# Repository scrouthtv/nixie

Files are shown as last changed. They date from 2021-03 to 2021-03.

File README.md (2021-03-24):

# About VFD tubes

<!--![Principle of VFD operation](./sources/futaba_concept.jpg)-->
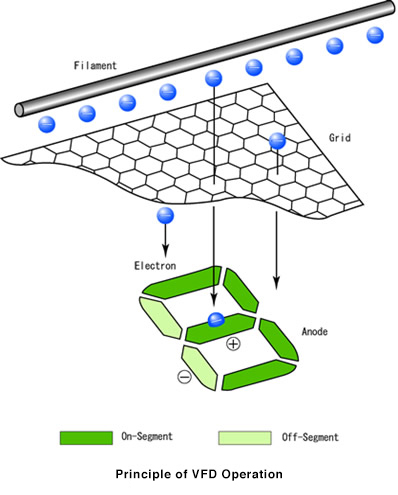
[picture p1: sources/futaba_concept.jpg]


The manufacturer has a [good explanation of the concept of VFD tubes](http://futaba.co.jp/en/display/vfd/index.html) on their website.

They basically work like this:
1. A *filament* (usually a Tungsten wire) is heated up and emits electrons into the vacuum in the tube.
2. The electrons are accelerated through a *grid* towards a positive-charged *anode*.
3. The electrons collide with the phosphor-coated anode and emit light due to [fluorescence](https://en.wikipedia.org/wiki/Fluorescence).

In the simplest case, the anodes make up an 8-figure consisting of seven individual segments plus a decimal point as an eigth segment.
[More complicated designs](http://futaba.co.jp/en/display/vfd/applications.html) such as combining multiple letters of different size, adding in symbols or [colors](https://en.wikipedia.org/wiki/Phosphorescence#Materials).

Each anode has its own wire leaving the casing.
The whole tube must be "activated" by setting the grid to a higher potential compared to the filament, which allows for multiplexing multiple tubes.

Image Source: [VFD | Futaba Corporation](http://futaba.co.jp/en/display/vfd/index.html)

# The tubes

I recently got ten VFD tubes labelled as **Futaba DG10Q1 3GS** out of an old calculator that was due for trash:

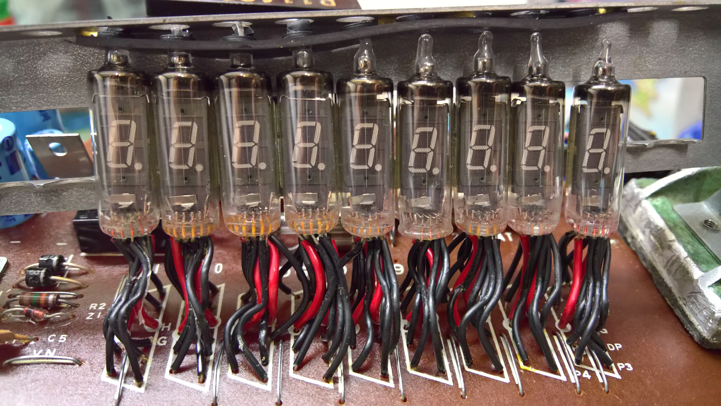
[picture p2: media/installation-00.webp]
The tubes installed in the calculator


The manufacturer has been ["selling gas-discharge display tube [since] 1968"](http://futaba.co.jp/en/files/notice_20200805.pdf). Sadly, they want to leave the business until the end of this year (2021).

The tubes themselves look fantastic:

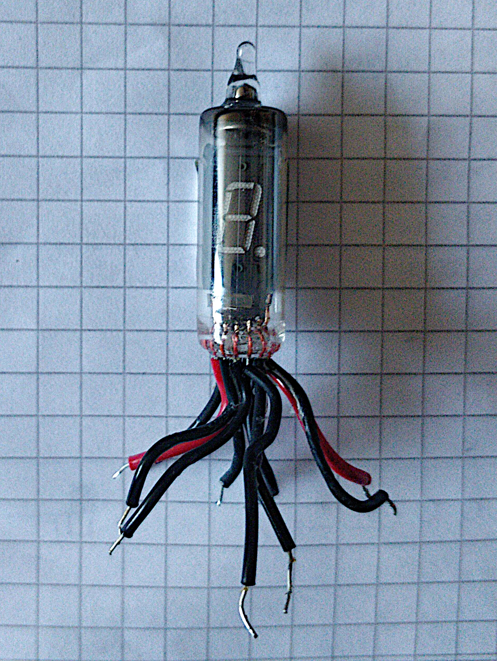
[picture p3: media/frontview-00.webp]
Frontview of the DG10Q1


Image Source: Used with permission, own work.

## Testing a tube

I wasn't able to find a datasheet online, only this image that circulates on the internet:

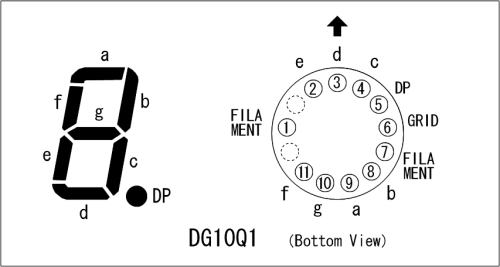
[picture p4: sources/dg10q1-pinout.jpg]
Pinout of the DG10Q1, bottom view


**Keep in mind that this is the bottom view.**

The filament in this tube is a thin wire in the front center that runs from the bottom to the top.
It glows orange-ish after applying a high enough current to it. 

My tubes have a set of red-colored wires for the filament. If yours don't, try to find the pair of pins wich has the lowest resistance (lower than 10 ohms). 

Slowly increasing the voltage across these two pins, they started glowing at around 0.8 V.

As a next step, I applied 18 V to both the grid and a segment to see it glowing.

Image Source: [DG10Q1 | AsahiNet](https://ne.jp/asahi/shared/o-family/ElecRoom/PARTS/DISPLAY/ElDG10Q1.html)

# My final circuit

I am planning on combining multiple tubes to get a "smart" clock which is controlled by an atmega328 chip (the chip that is also used in an Arduino).
The atmega can then be combined with a Raspberry Pi which controls the displayed text. 

In the end, I'll need at least a 5 V power supply for the logic.

## The filament driver

The filament basically carries all the load of the tube.
I found that a single DG10Q1 consumes up to 50 mA at 1 V!

The easiest way would be to use a voltage regulator which creates 1 V from my 5 V supply.
However, many common voltage regulators use a reference voltage of 1.25 V (e.g. [LM317](https://ti.com/lit/ds/symlink/lm317.pdf) or [MAX1733](https://datasheets.maximintegrated.com/en/ds/MAX1733-MAX1734.pdf)) and can't be adjusted to anything below 1.25 V ([without an overly complicated circuit](https://electronics.stackexchange.com/questions/116842/very-low-voltage-regulator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)).

Because of this issue, I am using a type of [current mirror circuit](https://wiki.analog.com/university/courses/electronics/text/chapter-11) instead:

Circuit used as the filament driver

Technically, it is used to mirror the amps from an input to the output.

However, with the correct value for R3, an arbitrary output voltage can be set.

*TODO: this is not correct and needs more work*

Image source: Own work.

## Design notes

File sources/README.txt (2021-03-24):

Further Reading
===============

*Nothing* in this folder is provided with permission of the original author.
I simply documented some things I came across that I found interesting, in case the original got taken down.

Sources:
 - futaba_vfd.pdf: http://futaba.co.jp/en/display/vfd/index.html. The original article on Futaba's website about the working principle of VFD tubes.
 - futaba_concept.jpg: http://futaba.co.jp/en/dbps_data/_material_/radicon_eng/Display_and_Module/vfd/images/whats_vfd02.jpg. The image along with the article.
 - futaba_vfd_applications.pdf: http://futaba.co.jp/en/display/vfd/applications.html. A glimpse at what can be done with VFD tubes.
 - dg10q1-pinout.jpg: Appears on https://ne.jp/asahi/shared/o-family/ElecRoom/PARTS/DISPLAY/ElDG10Q1.html as well as https://surplussales.com/Bulbs-Incan-Panel/Close-ups/lmp-dg10a.html and https://radiomuseum.org/tubes/tube_dg10q1.html. Pinout for a DG10Q1 or comparable, bottom view.

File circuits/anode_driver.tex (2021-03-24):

\documentclass[margin = 24mm]{standalone}

\usepackage{xcolor}

\usepackage{mathspec}
\setallmainfonts(Digits,Latin){osifont.ttf}

\usepackage{siunitx}
\sisetup{locale = DE, retain-explicit-plus}

\usepackage[european]{circuitikz}

\begin{document}
	\begin{circuitikz}[]
		\node [nigfete] (fet) at (3, -.75) {Q};
		\draw (0, -1) to [short, o-] (fet.G);
		\node [above] at (0, -1) { \SI{+5}{\volt} };

		\node [diodetube, filament, nocathode] (tube) at (5, -.5) {};
		\node [right] at (tube.east) {V};

		\draw (fet.S) to node[rground] {} ++(0, 0);

		\draw (fet.D) to [R = R] ++(-2.5, 0) to [short, -o] ++(-.5, 0)
			node[above] { \SI{+20}{\volt} };
		\draw (fet.D) [short, *-] to ++(0, 1) -| (tube.anode);
	\end{circuitikz}
\end{document}

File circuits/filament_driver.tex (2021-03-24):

\documentclass[margin = 24mm]{standalone}

\usepackage{mathspec}
\setallmainfonts(Digits,Latin){osifont.ttf}

\usepackage{siunitx}
\sisetup{locale = DE, retain-explicit-plus}

\usepackage[european]{circuitikz}

\begin{document}
	\begin{circuitikz}[]
		% left pnp
		\node [pnp, xscale = -1] (Q1) at (2, -3) {\ctikzflipx{$Q_1$}};
		\draw (2, 0) to [R = $R_1$] (Q1.E);

		% resistor to ground
		\draw (Q1.C) to [R = $R_2$] ++(0, -2) to node[rground] {} ++(0, 0);

		% right pnp
		\node [pnp] (Q2) at (4.5, -3) {$Q_2$};
		\path (4.5, 0) -- (Q2.E) coordinate [pos = .5] (dmid);
		\draw (4.5, 0) to [empty diode] (dmid) to [empty diode] (Q2.E);

		% resistor to ground
		\draw (Q2.C) to [R = $R_3$] ++(0, -2) to node[rground] {} ++(0, 0);

		% connect the first collector to the bases
		\path (Q1.C) -- ++(0, -2) coordinate [pos = 0] (bceout);
		\draw (Q1.B) -- (Q2.B) coordinate [pos = .2] (bcein);
		\draw (bceout) -| (bcein);
		\path (bceout) to [short, *-*] (bcein);

		% third resistor, this one's carrying all the load:
		\path (Q2.C) -- ++(3, 0) coordinate [pos = 1] (q2pos);
		\node [npn, scale = 1.3] (Q3) at (q2pos) {$Q_3$};
		\draw (Q2.C) to [short, *-] (Q3.B);

		% connect everything to +5V:
		\node [above] at (0, 0) { \SI{+5}{\volt} };
		\draw (0, 0) to [short, o-*] (2, 0) to [short, -*] (4.5, 0) -| (Q3.C);

		% output node:
		\draw (Q3.E) to [short, -o] ++(1, 0);
		\path (Q3.E) -- ++(1, 0) node[pos = 1, above] {$V_{out}$};

	\end{circuitikz}
\end{document}

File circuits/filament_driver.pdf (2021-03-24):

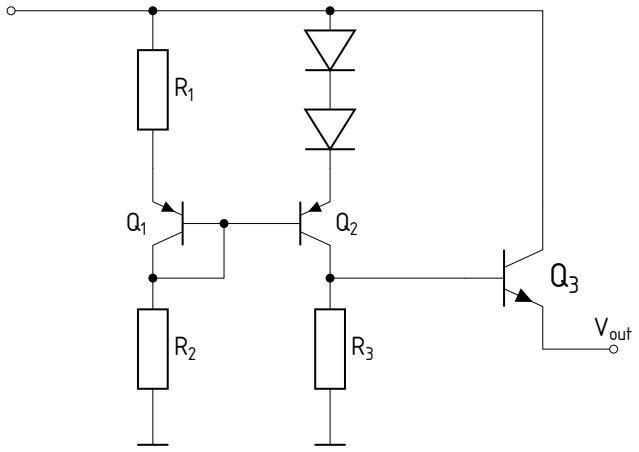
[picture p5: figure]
Vout

+5 V

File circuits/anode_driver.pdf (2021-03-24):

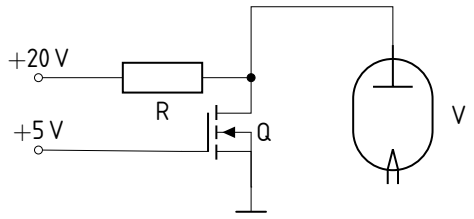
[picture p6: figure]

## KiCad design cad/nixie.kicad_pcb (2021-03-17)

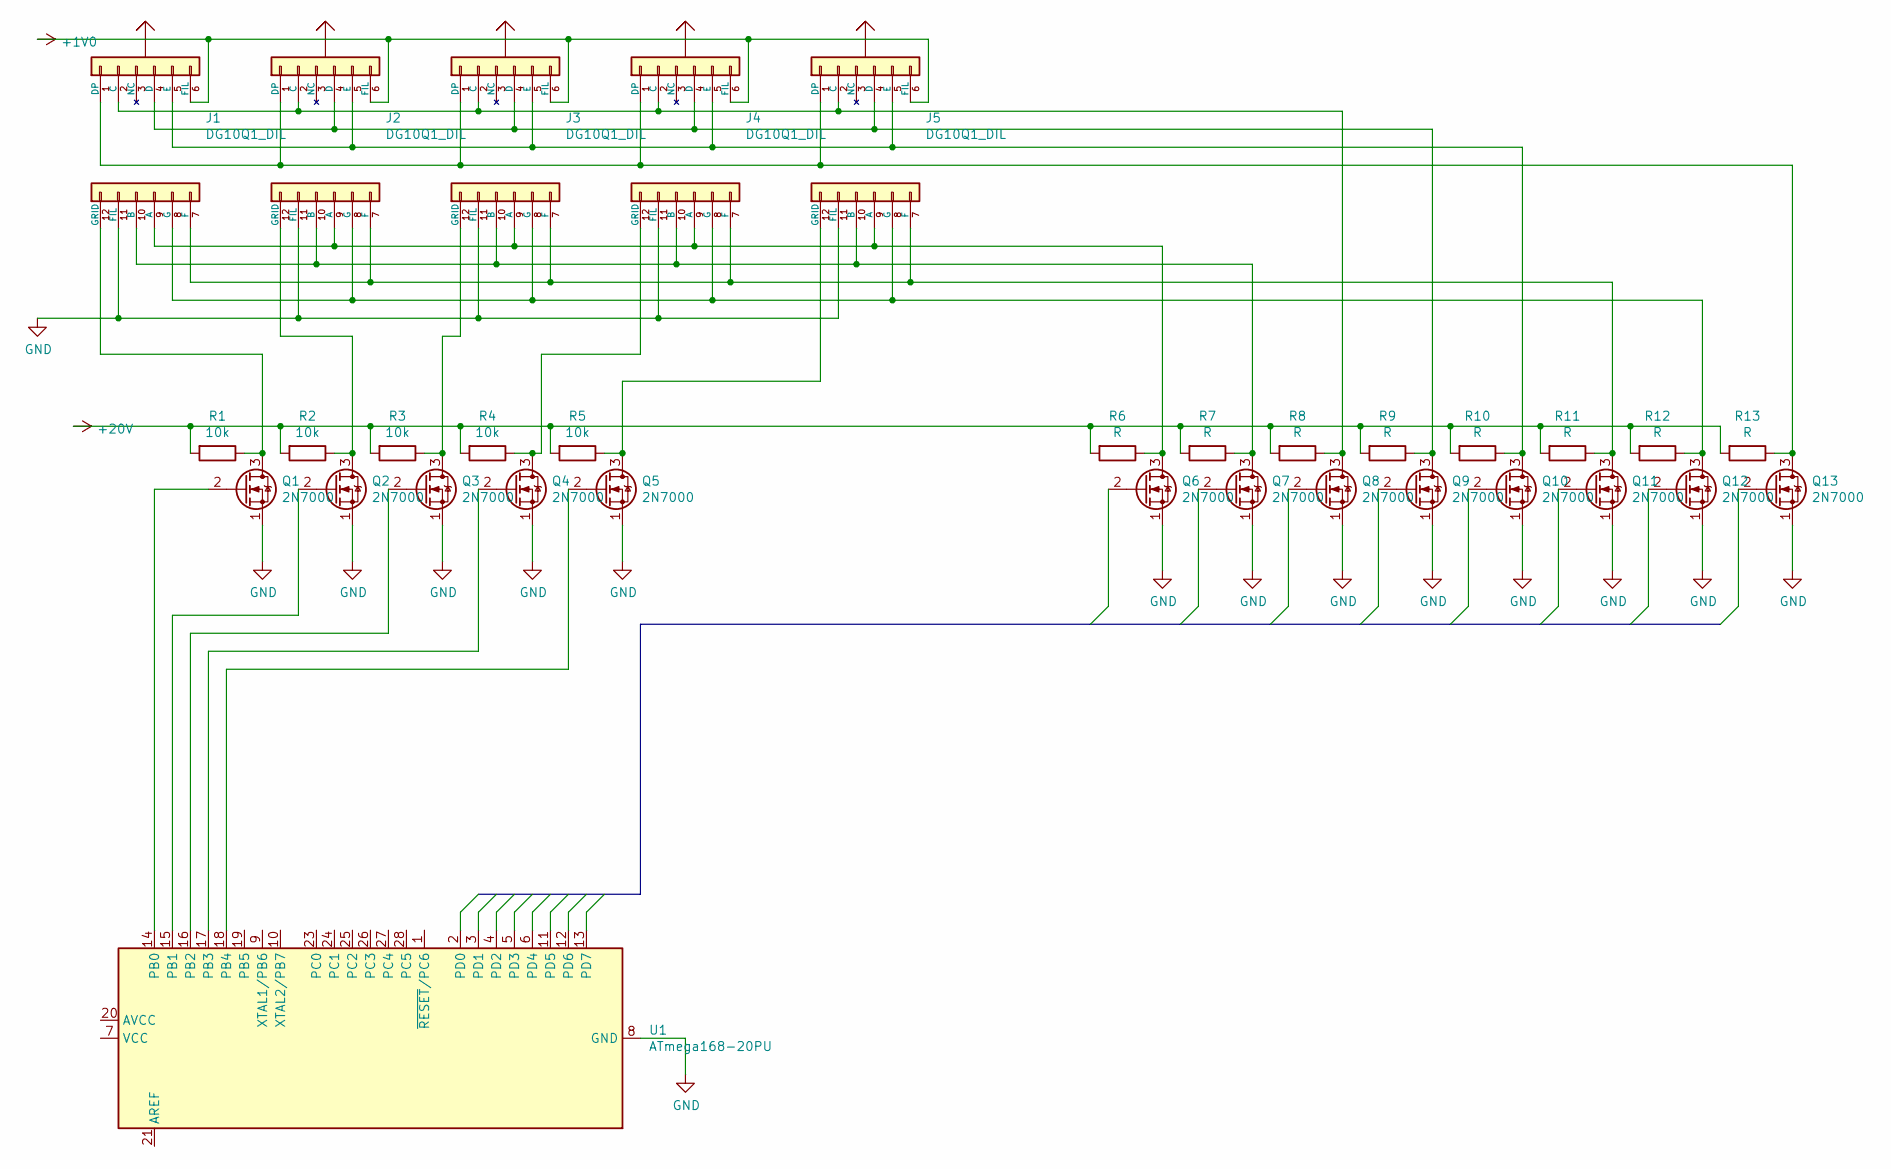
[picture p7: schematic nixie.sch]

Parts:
J1, J2, J3, J4, J5: DG10Q1_DIL; DG10Q1_DIL_2.54mm
Q1, Q2, Q3, Q4, Q5, Q6, Q7, Q8, Q9, Q10, Q11, Q12, Q13: 2N7000; TO-92_Inline
R1, R2, R3, R4, R5: 10k; R_Axial_DIN0207_L6.3mm_D2.5mm_P10.16mm_Horizontal
R6, R7, R8, R9, R10, R11, R12, R13: R; R_Axial_DIN0207_L6.3mm_D2.5mm_P10.16mm_Horizontal
U1: ATmega168-20PU; DIP-28_W7.62mm

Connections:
+1V0: J1.6 (FIL), J2.6 (FIL), J3.6 (FIL), J4.6 (FIL), J5.6 (FIL)
+20V: R1.2, R2.2, R3.2, R4.2, R5.2, R6.2, R7.2, R8.2, R9.2, R10.2, R11.2, R12.2, R13.2
GND: J1.11 (FIL), J2.11 (FIL), J3.11 (FIL), J4.11 (FIL), J5.11 (FIL), Q1.1 (S), Q2.1 (S), Q3.1 (S), Q4.1 (S), Q5.1 (S), Q6.1 (S), Q7.1 (S), Q8.1 (S), Q9.1 (S), Q10.1 (S), Q11.1 (S), Q12.1 (S), Q13.1 (S), U1.8 (GND), U1.22 (GND)
unnamed: J1.1 (DP), J2.1 (DP), J3.1 (DP), J4.1 (DP), J5.1 (DP), Q13.3 (D), R13.1
unnamed: J1.2 (C), J2.2 (C), J3.2 (C), J4.2 (C), J5.2 (C), Q8.3 (D), R8.1
unnamed: J1.4 (D), J2.4 (D), J3.4 (D), J4.4 (D), J5.4 (D), Q9.3 (D), R9.1
unnamed: J1.5 (E), J2.5 (E), J3.5 (E), J4.5 (E), J5.5 (E), Q10.3 (D), R10.1
unnamed: J1.7 (F), J2.7 (F), J3.7 (F), J4.7 (F), J5.7 (F), Q11.3 (D), R11.1
unnamed: J1.8 (G), J2.8 (G), J3.8 (G), J4.8 (G), J5.8 (G), Q12.3 (D), R12.1
unnamed: J1.9 (A), J2.9 (A), J3.9 (A), J4.9 (A), J5.9 (A), Q6.3 (D), R6.1
unnamed: J1.10 (B), J2.10 (B), J3.10 (B), J4.10 (B), J5.10 (B), Q7.3 (D), R7.1
unnamed: J1.12 (GRID), Q1.3 (D), R1.1
unnamed: J2.12 (GRID), Q2.3 (D), R2.1
unnamed: J3.12 (GRID), Q3.3 (D), R3.1
unnamed: J4.12 (GRID), Q4.3 (D), R4.1
unnamed: J5.12 (GRID), Q5.3 (D), R5.1
unnamed: Q1.2 (G), U1.14 (PB0)
unnamed: Q2.2 (G), U1.15 (PB1)
unnamed: Q3.2 (G), U1.16 (PB2)
unnamed: Q4.2 (G), U1.17 (PB3)
unnamed: Q5.2 (G), U1.18 (PB4)

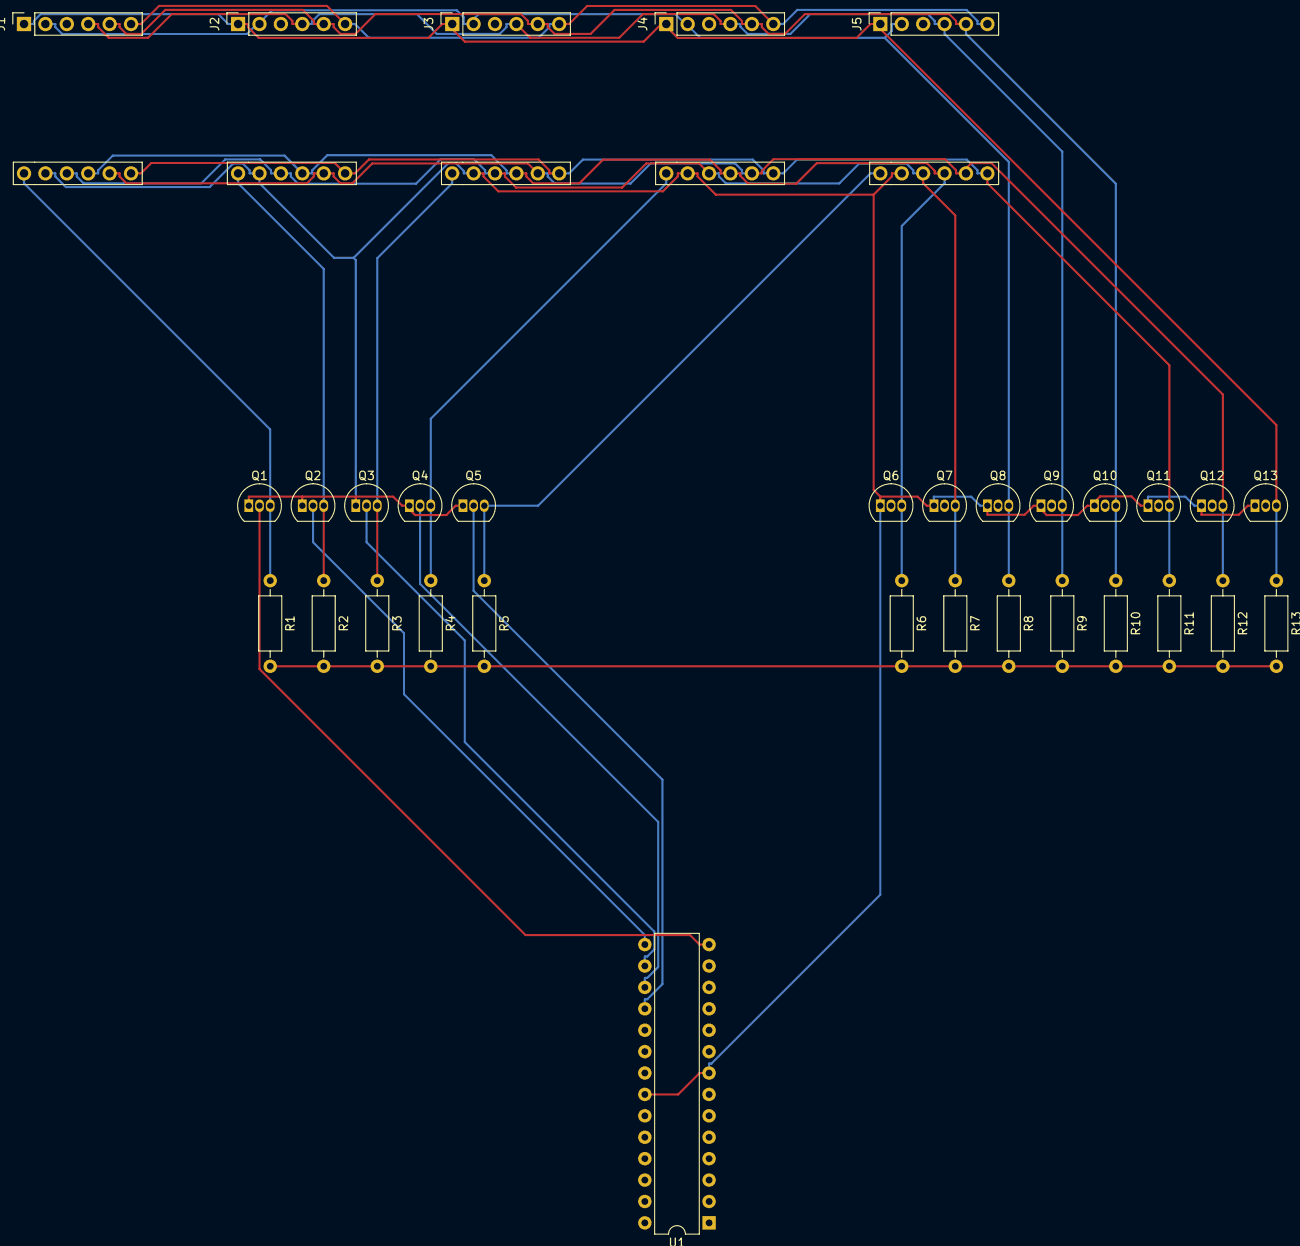
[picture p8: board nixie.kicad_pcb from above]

Board: 2 copper layers, 32 parts (0 on the bottom side), 21 nets.

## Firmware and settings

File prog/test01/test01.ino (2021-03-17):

#define GRID1 12
#define GRID2 10
#define ANODA 13
#define ANODB 6
#define ANODC 7
#define ANODD 2
#define ANODE 3
#define ANODF 9
#define ANODG 11
#define ANODP 8

void setup() {
  Serial.begin(9600);

  pinMode(GRID1, OUTPUT);
  pinMode(GRID2, OUTPUT);
  
  pinMode(ANODA, OUTPUT);
  pinMode(ANODB, OUTPUT);
  pinMode(ANODC, OUTPUT);
  pinMode(ANODD, OUTPUT);
  pinMode(ANODE, OUTPUT);
  pinMode(ANODF, OUTPUT);
  pinMode(ANODG, OUTPUT);
  pinMode(ANODP, OUTPUT);
}

void loop() {
  digitalWrite(GRID1, LOW);
  digitalWrite(GRID2, HIGH);
  digitalWrite(ANODA, HIGH);
  digitalWrite(ANODB, HIGH);
  digitalWrite(ANODC, HIGH);
  digitalWrite(ANODD, HIGH);
  digitalWrite(ANODE, LOW);
  digitalWrite(ANODF, LOW);
  digitalWrite(ANODG, LOW);
  digitalWrite(ANODP, LOW);
  delay(1000);
  Serial.println("B2");
  digitalWrite(GRID1, HIGH);
  digitalWrite(GRID2, LOW);
  digitalWrite(ANODA, LOW);
  digitalWrite(ANODB, LOW);
  digitalWrite(ANODC, LOW);
  digitalWrite(ANODD, LOW);
  digitalWrite(ANODE, HIGH);
  digitalWrite(ANODF, HIGH);
  digitalWrite(ANODG, HIGH);
  digitalWrite(ANODP, HIGH);
  delay(1000);
}

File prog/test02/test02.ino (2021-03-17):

#define GRID1 10
#define GRID2 12
#define ANODA 13
#define ANODB 6
#define ANODC 7
#define ANODD 2
#define ANODE 3
#define ANODF 9
#define ANODG 11
#define ANODP 8

#define MULTIPLEX_DELAY 5 // [ms]

byte text[] = {
  0b01101110, // H
  0b11101110, // A
  0b00011100, // L
  0b00011100, // L
  0b11111100, // O
  0b00000000, // _
  0b01111100, // U
  0b10011110, // E
  0b00011100, // L
  0b00011111, // t.
  0b00000000, // _
  0b00000000, // _
};

          // abcdefgp
byte one = text[0];
byte two = text[1];

int position = 0;
unsigned long lastPositionStart = 0;
  

void setup() {
  Serial.begin(9600);

  pinMode(GRID1, OUTPUT);
  pinMode(GRID2, OUTPUT);
  
  pinMode(ANODA, OUTPUT);
  pinMode(ANODB, OUTPUT);
  pinMode(ANODC, OUTPUT);
  pinMode(ANODD, OUTPUT);
  pinMode(ANODE, OUTPUT);
  pinMode(ANODF, OUTPUT);
  pinMode(ANODG, OUTPUT);
  pinMode(ANODP, OUTPUT);
}

void loop() {
  // write the first digit
  digitalWrite(GRID1, HIGH);
  digitalWrite(GRID2, LOW);
  digitalWrite(ANODA, (one & 0b10000000) == 0 ? HIGH : LOW);
  digitalWrite(ANODB, (one & 0b01000000) == 0 ? HIGH : LOW);
  digitalWrite(ANODC, (one & 0b00100000) == 0 ? HIGH : LOW);
  digitalWrite(ANODD, (one & 0b00010000) == 0 ? HIGH : LOW);
  digitalWrite(ANODE, (one & 0b00001000) == 0 ? HIGH : LOW);
  digitalWrite(ANODF, (one & 0b00000100) == 0 ? HIGH : LOW);
  digitalWrite(ANODG, (one & 0b00000010) == 0 ? HIGH : LOW);
  digitalWrite(ANODP, (one & 0b00000001) == 0 ? HIGH : LOW);

  delay(MULTIPLEX_DELAY);
  
  digitalWrite(GRID1, LOW);
  digitalWrite(GRID2, HIGH);
  digitalWrite(ANODA, (two & 0b10000000) == 0 ? HIGH : LOW);
  digitalWrite(ANODB, (two & 0b01000000) == 0 ? HIGH : LOW);
  digitalWrite(ANODC, (two & 0b00100000) == 0 ? HIGH : LOW);
  digitalWrite(ANODD, (two & 0b00010000) == 0 ? HIGH : LOW);
  digitalWrite(ANODE, (two & 0b00001000) == 0 ? HIGH : LOW);
  digitalWrite(ANODF, (two & 0b00000100) == 0 ? HIGH : LOW);
  digitalWrite(ANODG, (two & 0b00000010) == 0 ? HIGH : LOW);
  digitalWrite(ANODP, (two & 0b00000001) == 0 ? HIGH : LOW);

  delay(MULTIPLEX_DELAY);

  if ((millis() - lastPositionStart) > 1000) {
    lastPositionStart = millis();
    position++;
    //Serial.println(text[position % sizeof(text)]);
    one = text[position % sizeof(text)];
    two = text[(position + 1) % sizeof(text)];
  }
  
}

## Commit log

2021-03-17 kicad files v1
    [nixie.kicad_pcb, nixie.sch]
2021-03-17 drawing of the anode driver
2021-03-24 filament driver
2021-03-24 testing a tube
